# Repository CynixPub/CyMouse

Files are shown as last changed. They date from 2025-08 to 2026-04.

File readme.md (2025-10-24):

[中文版本 🇨🇳](./readme_cn.md)

# CyMouse: A High-Performance Mouse with Health Monitoring

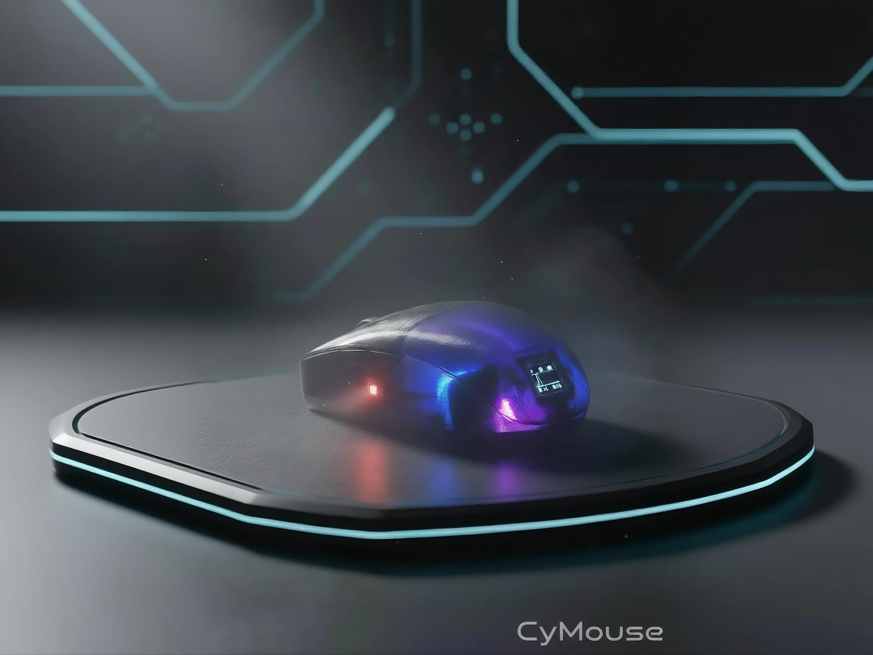
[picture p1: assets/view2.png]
CyMouse Preview


**CyMouse** is a high-performance mouse that supports health monitoring. It is powered by an **ESP32-S3FH4R2** controller and equipped with a **PAW3395DM-T6QU** sensor. It also integrates SpO₂ and heart rate sensors, as well as a built-in display for viewing mouse status and configuring settings.

---

## ✨ Background

Due to the nature of my work, I spend long hours sitting in front of a computer. This made me wonder — could there be a product that monitors our health unobtrusively?

Currently, most health monitoring devices are wristbands or smartwatches. However, I personally dislike wearing them while working because they often bump against the keyboard. Health monitoring sensors need close contact with the body — usually the wrist or fingers. In the workplace, the peripheral we touch the most is undoubtedly the **mouse**.

Thus, the idea of integrating health monitoring into a mouse was born — and that’s how **CyMouse** came to life.

---

## 🚀 Key Features

### 🖱️ Mouse Features

- **Tri-mode connectivity**: USB-C wired, Bluetooth, and 2.4G wireless.  
- **High-performance sensor**: PAW3395DM-T6QU sensor, up to 26,000 DPI.  
- **Quick DPI switching**: Dedicated DPI button on the bottom for easy adjustment.

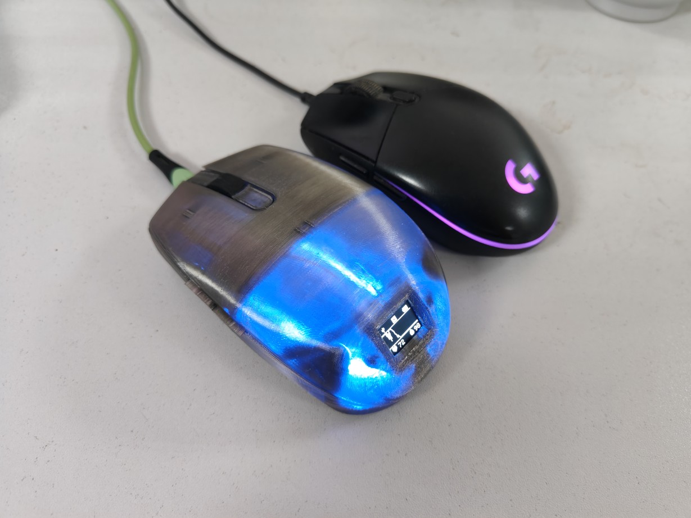
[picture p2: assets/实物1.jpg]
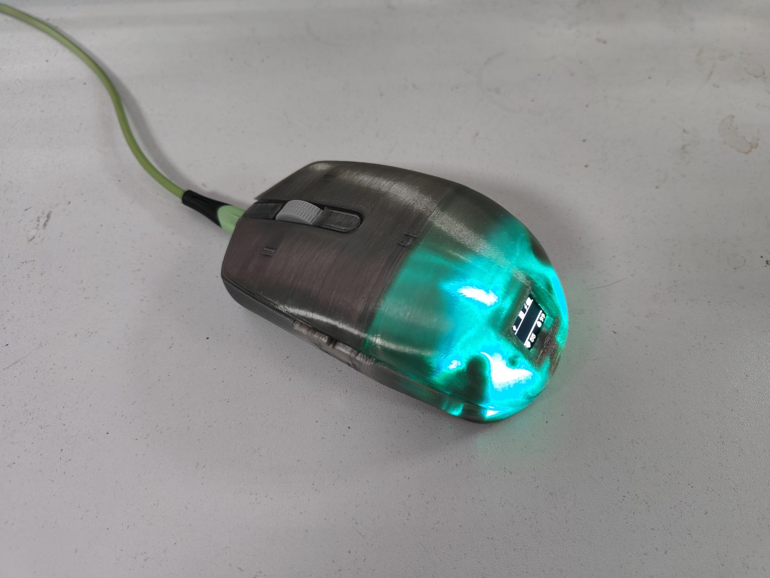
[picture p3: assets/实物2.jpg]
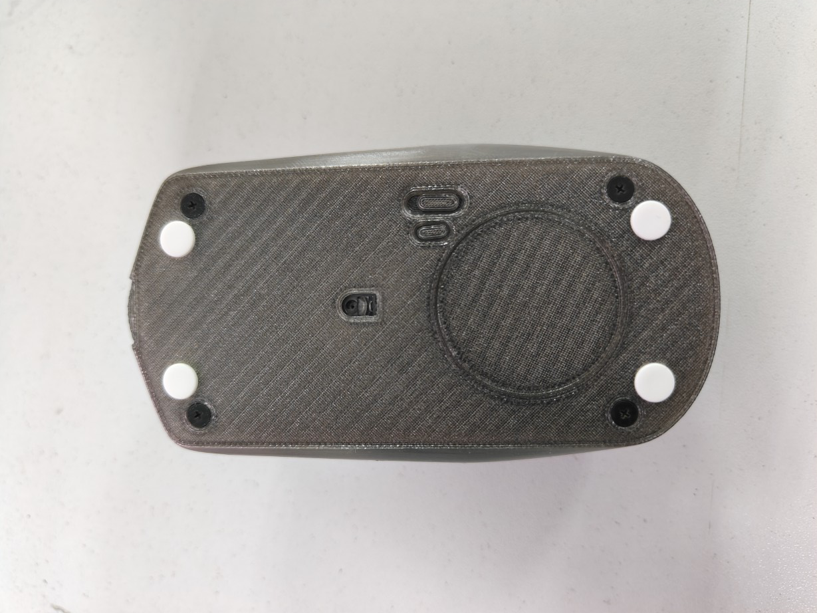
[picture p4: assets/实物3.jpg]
      

#### Performance Data

- **USB / Wireless Mode**:  
  Due to the ESP32-S3’s USB Full-Speed (12 Mbit/s) limitation, the maximum polling rate is 1 kHz. While this doesn’t fully unleash the PAW3395DM-T6QU’s capabilities, the actual experience is smoother and more precise than my Logitech G102 — more than enough for office use and gaming (including FPS titles).

  *(Performance charts omitted for brevity — same as original)*

- **Bluetooth Mode**:  
  Performance is slightly limited by BLE protocol constraints but is perfectly sufficient for office use.

  *(Performance charts omitted for brevity — same as original)*

- **Mouse Weight**:  
  Base weight: 83 g; with battery: approximately 110.4 g.

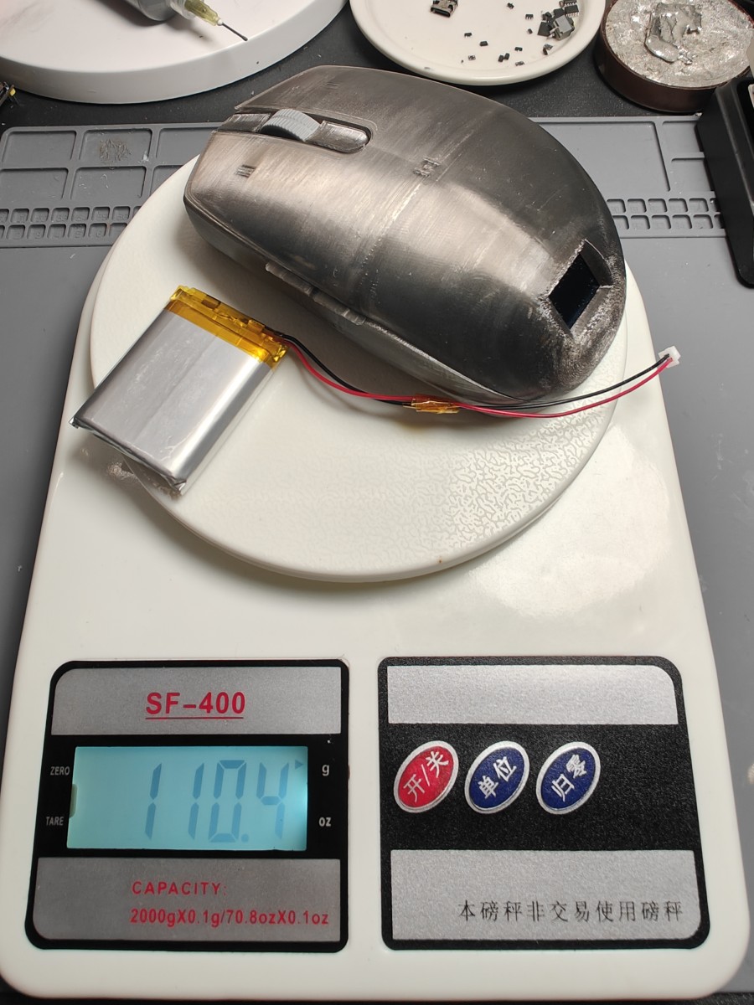
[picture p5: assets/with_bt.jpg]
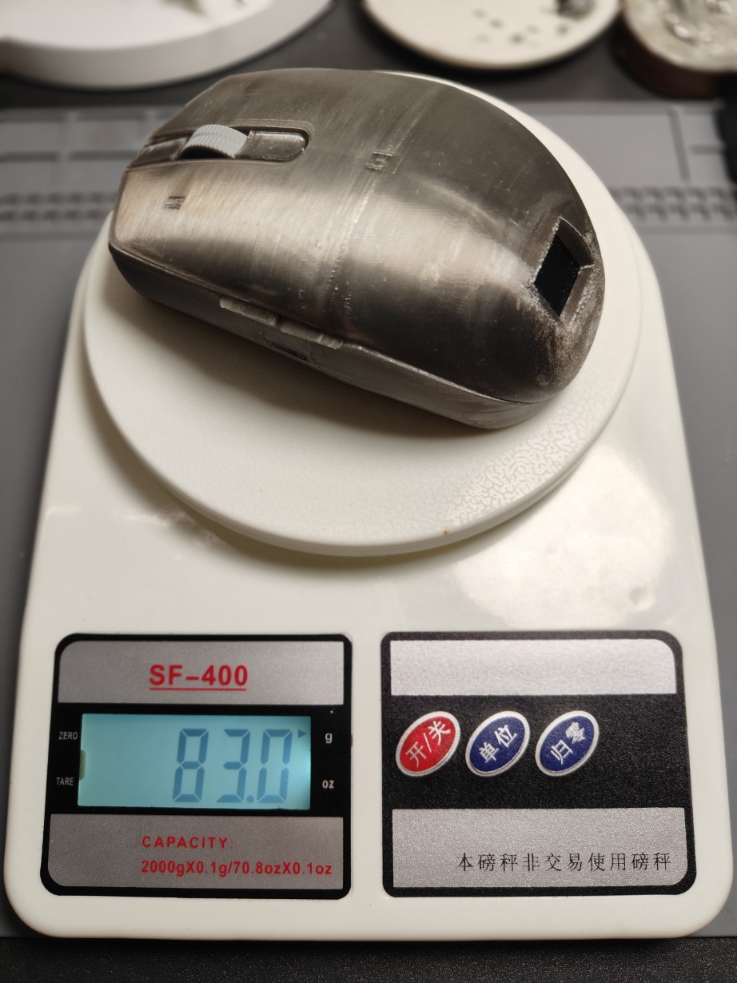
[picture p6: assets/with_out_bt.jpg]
   

---

### ❤️ Health Monitoring

- **Multi-dimensional data**: Supports SpO₂, heart rate, fatigue index, microcirculation, blood pressure, cardiac output, peripheral resistance, and more.  
- **Smart reminders**: Vibration-based sedentary alerts.

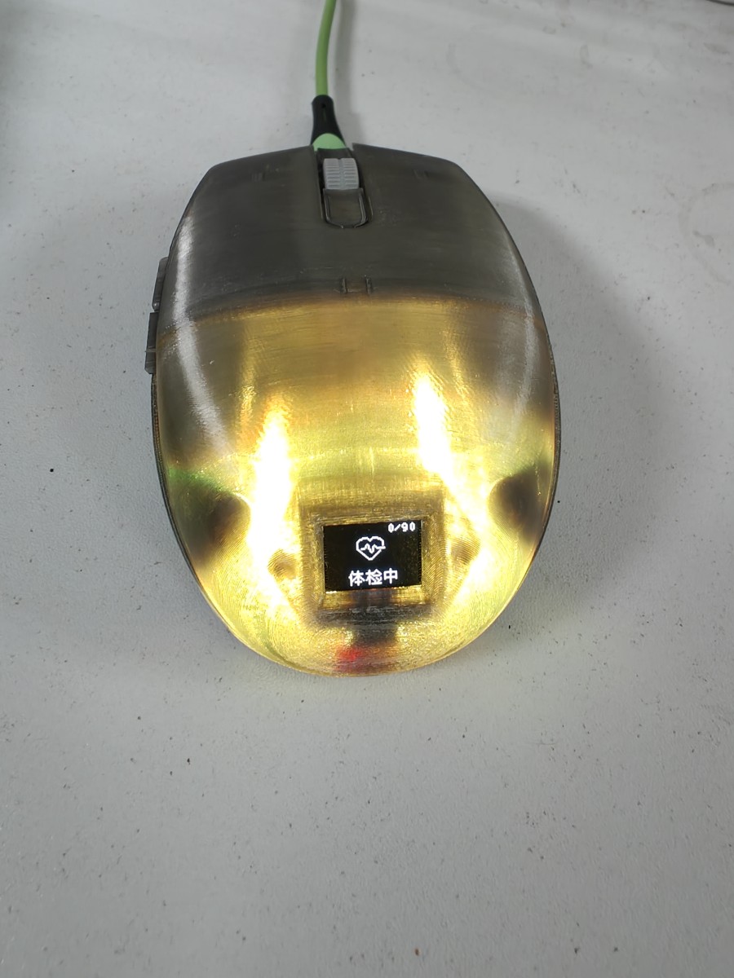
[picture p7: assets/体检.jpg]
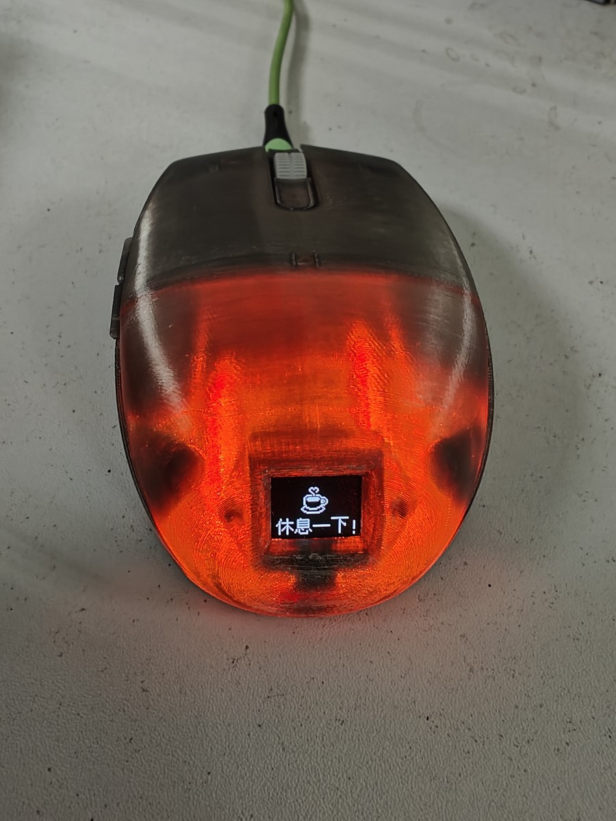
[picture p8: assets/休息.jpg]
   

*(Note: Current lighting effects use random colors.)*

---

### 💡 Additional Features

- Adjustable DPI and scroll speed  
- Customizable on-screen animations during movement  
- RGB lighting effects  
- Health and mouse data history  
- Multi-language support  

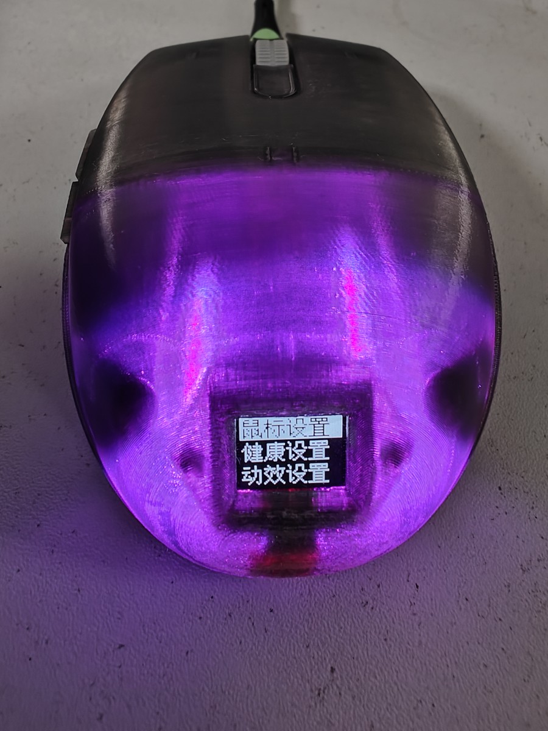
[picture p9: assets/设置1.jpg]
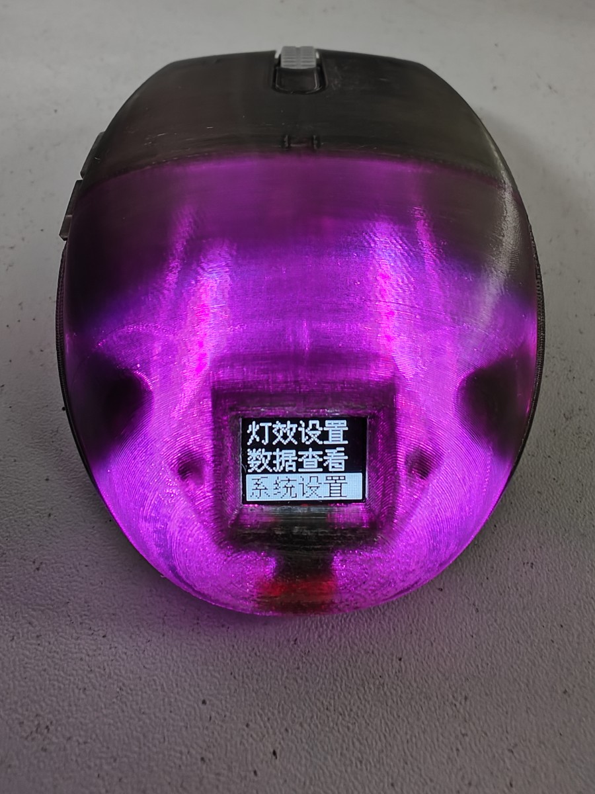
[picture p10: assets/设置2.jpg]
   

---

### 💻 PC Client

In USB mode, the PC client can:

- View historical health monitoring data  
- Manually initiate a new health check  
- Display usage statistics for the mouse  

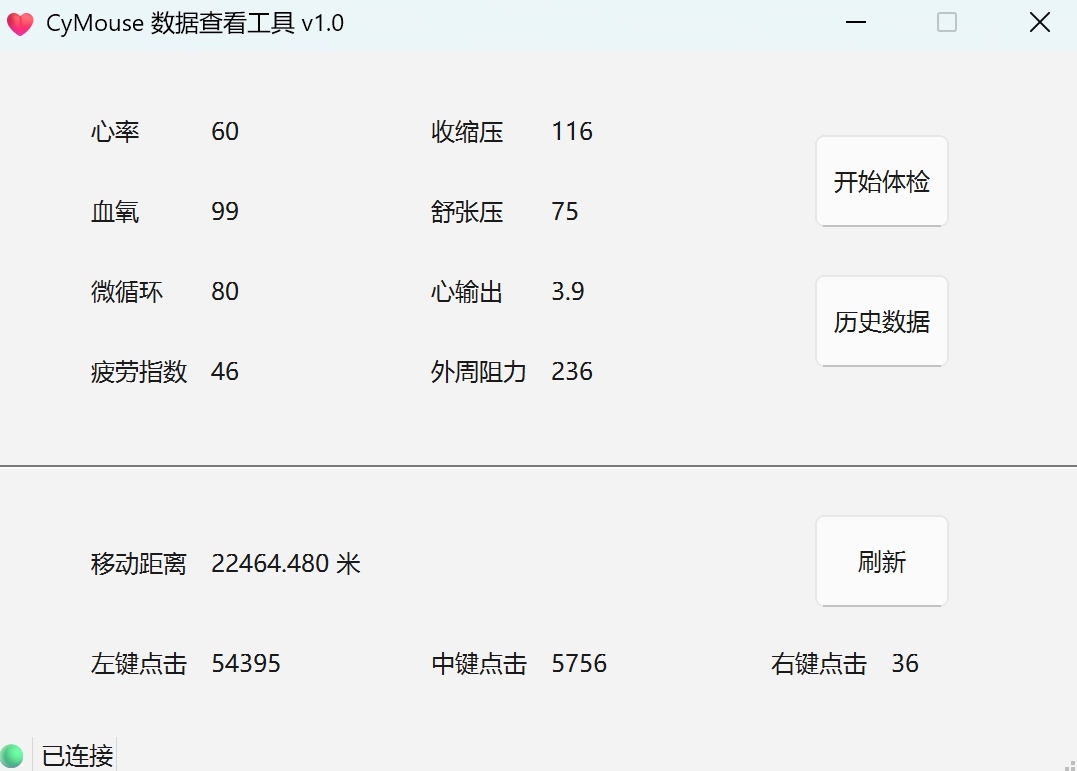
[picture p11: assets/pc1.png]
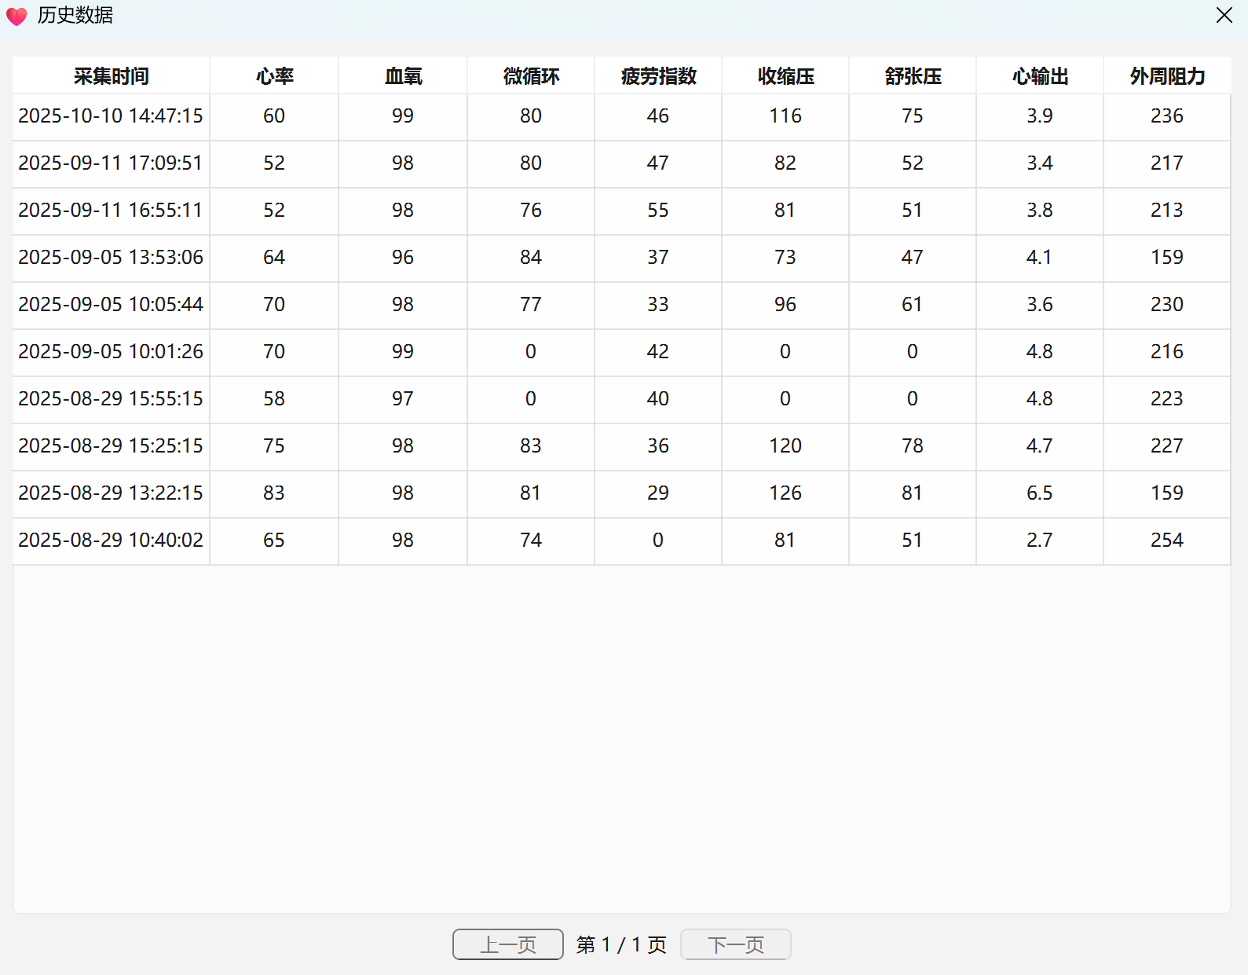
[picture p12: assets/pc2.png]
   

---

## 🛠️ Hardware Customization and Assembly

Hardware resources are open source. You can find them here:  
- **Open-source repository**: https://oshwlab.com/keivenliao/cymouse

### Procurement Notes

Most components are available on LCSC. If out of stock, you may source alternatives elsewhere. Special parts include:

- **Sensor**: PAW3395DM-T6QU (with lens model `LM19-LSI`)  
- **SpO₂ Module**: Custom module supporting blood pressure monitoring; includes 6-pin cable and 3D model matched to its dimensions  
- **Display**: 0.66" OLED, `64×48` resolution, `16PIN` interface (ensure connector matches reference image)  
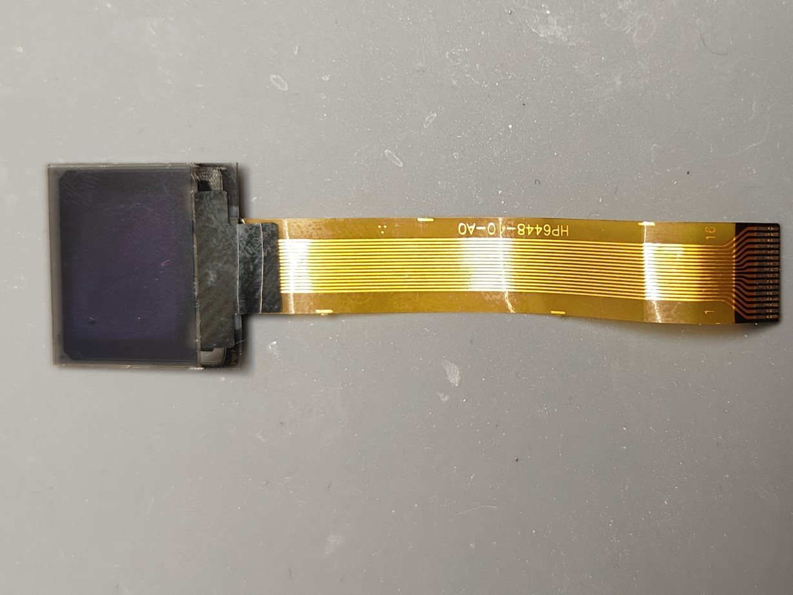
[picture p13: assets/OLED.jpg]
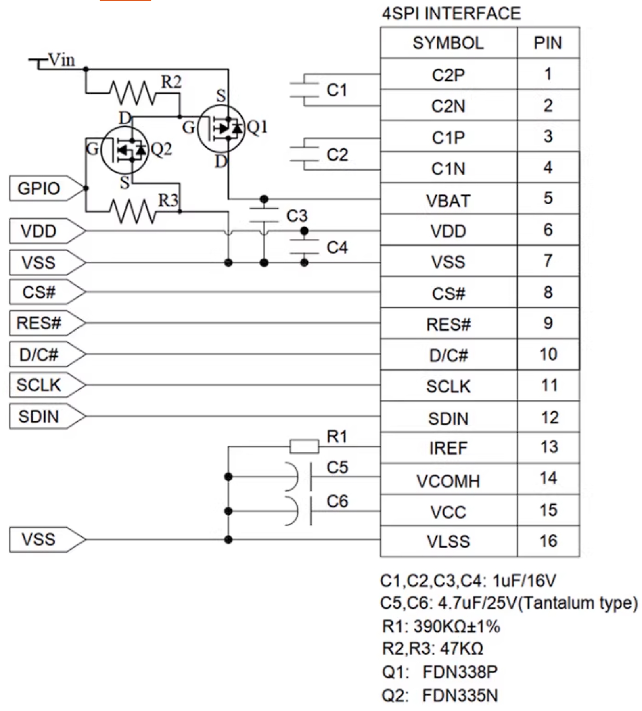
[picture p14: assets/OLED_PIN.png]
     
- **Battery**: `103443-1500mAh` (10×34×43 mm), ~48 hrs continuous use; optional if using USB mode only  
- **Battery Cable**: `2P 1.25mm` male, 50mm length  
- **USB Cable**: Flexible USB 2.0 Type-C for optimal wired performance  
- **Switches**: TTC Dustproof Gold (0.65N), or compatible  
- **Encoder**: TTC Dustproof Gold wheel encoder (12mm height)  
- **Middle Button**: Kailh Silent (9.5mm height)  
- **Scroll Wheel**: Compatible with Logitech G102 / G304 / G305  
- **Feet Pads**: 7mm diameter ice-type dots  
- **Screws and Nuts**: *(details same as original)*  
- **FPC Cable**: `4P`, `0.5mm` pitch, same direction, 5cm length  

### Soldering & Assembly Notes

- **Chip orientation**: Ensure `TPS61222DCKR` and both `TPS22919QDCKRQ1` chips align with PCB markings.  
- **Connector orientation**: Check 4-pin and 6-pin headers carefully.  
- **SpO₂ FPC cable**: Orientation **must** match the reference; incorrect direction may damage the module!  

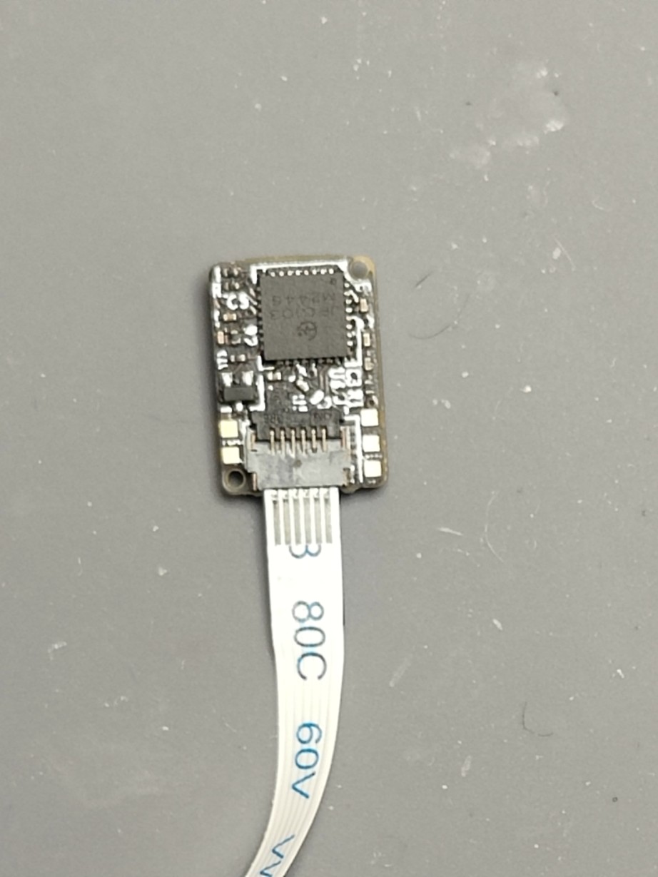
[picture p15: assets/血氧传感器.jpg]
  

---

### Core Circuit Design

- **Charging Chip**: TI `BQ24075RGTR` (supports power path management) instead of common `TP4056`.  
- **Main Power**: `TLV62569DBVR` DCDC instead of LDO for reduced heat and higher efficiency.  
- **RGB LED Power**: `TPS61222DCKR` boosts 3.3V→5V for stable illumination; combined with `TPS22919QDCKRQ1` load switch for MCU-controlled power-off.

---

### 3D Model & Printing

- Model split into top cover, top support, base, and small parts.  
- Designed in Autodesk Fusion 360 (source files provided).  
- Printable directly via included Bambu Studio project files.  
- Recommended material: **translucent PETG** for best LED lighting effects.  

*(Assembly and support adjustment details same as original)*

---

## 💾 Firmware Flashing & Usage

### Flashing Guide

- **Mouse firmware**: Flash the **full firmware** first. For later updates, use **upgrade firmware** to retain activation and history.  
- **Wireless receiver**: Any ESP32-S3 (with R2 Flash/RAM) board works. Receiver firmware is open-source and adaptable.  

### Activation

Firmware is closed-source. On first boot, scan the on-screen QR code to obtain a **free lifetime activation code**.

> **Tips**:
> - Avoid using WeChat scanner (browser limitation)  
> - Use your phone’s camera, browser, or Alipay  
> - If redirect fails, connect to Wi-Fi hotspot `CyMouse_xxxx` (password `12345678`) to auto-open activation page  
> - Retrieve activation code at: https://cynix.cc/license/activate  

### Usage

- **Enter Settings**: Hold both side buttons for 3 seconds.  

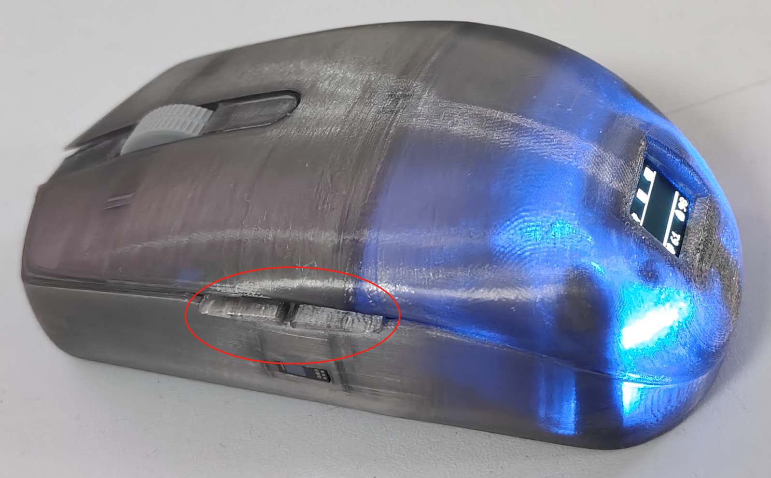
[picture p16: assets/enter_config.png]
  

---

### 🔋 Unverified Features

Hardware design includes wireless charging support with reserved module space, though it hasn’t been tested yet. Follow for updates.

---

## 📜 Open Source & Privacy

- **Open components**: Hardware (PCB), 3D model, receiver firmware, and PC client.  
  - Hardware: https://oshwhub.com/keivenliao/cymouse  
  - Receiver: https://github.com/CynixPub/CyMouse_Receiver  
  - PC Client: https://github.com/CynixPub/PC_monitor  
- **User Privacy**: Mouse firmware works fully offline; PC client stores data locally.  
- **Licenses**: CC BY-NC-SA 4.0 / GPLv3.

---

## 🙏 Acknowledgments

Inspired by the following projects:

- https://github.com/Ghost-Girls/PMW3360-3389-PAW3395_STM32-CH32-APM32  
- https://github.com/Li-Dongze/stm32_paw3395_mouse  
- https://github.com/kirltrz/PAW3395_Arduino_ESP32  

---

## ✍️ Final Words

Technically, the PC client could configure all mouse features, but that would defeat the purpose — I wanted all settings adjustable directly **on the mouse display**. (Also, I’ll admit... a bit of laziness 😄)

Hardware development isn’t easy — I’ve gone through countless trials, especially with 3D model fitting. Here are some of the **“sacrifices”** made along the way:

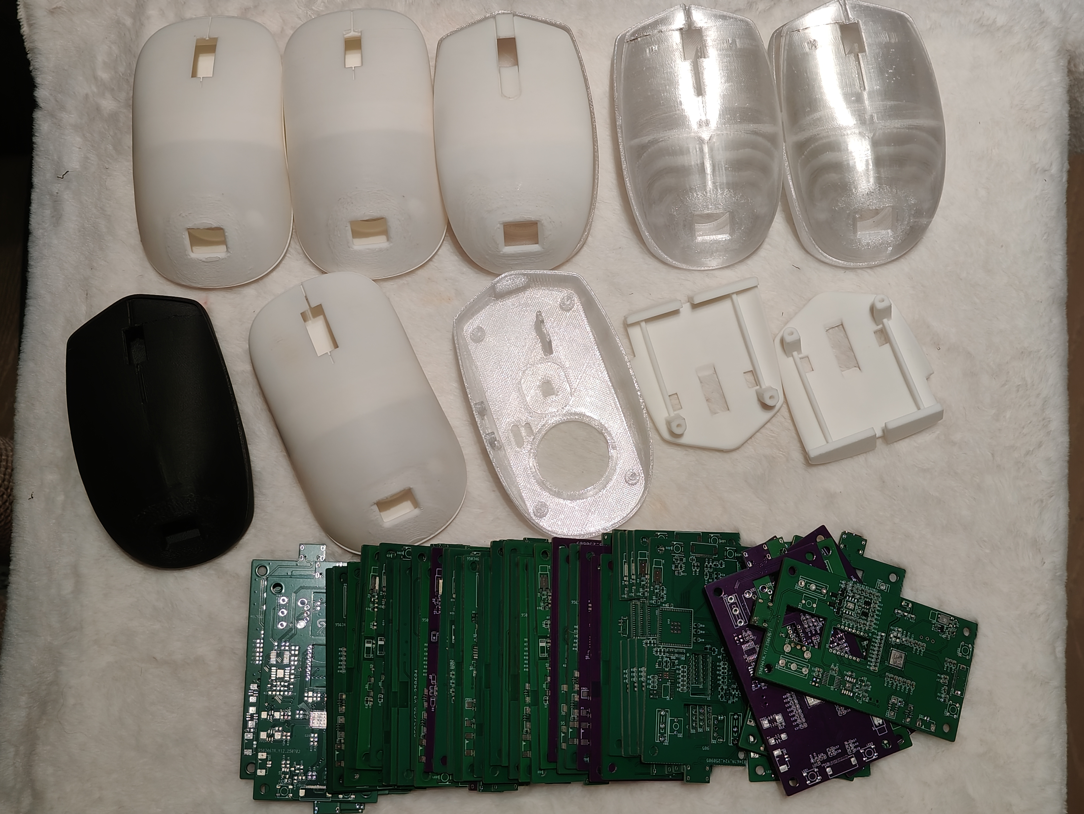
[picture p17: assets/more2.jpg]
  

---

## ❤️ Donation

If CyMouse has been helpful to you, consider supporting me — it helps improve and maintain this project.

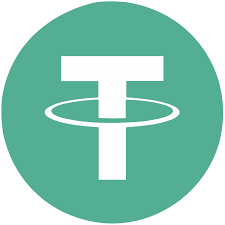
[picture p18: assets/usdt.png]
   TFexGjjxHDo7EsU6x8Yiz7Eu2kqVYpnEw1

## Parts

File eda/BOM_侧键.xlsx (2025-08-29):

No. | Quantity | Comment | Designator | Footprint | Value | Manufacturer Part | Manufacturer | Supplier Part | Supplier
1 | 1 | AFC01-S04FCC-00 | FPC1 | FFC-SMD_4P-P0.50_AFC01-S04FCC-00 |  | AFC01-S04FCC-00 | JS(钜硕电子) | C262260 | LCSC
2 | 2 | TS-1007S-AR02516 | SW23,SW24 | SW-SMD_L6.1-W3.6-LS7.9 |  | TS-1007S-AR02516 | XUNPU(讯普) | C720381 | LCSC

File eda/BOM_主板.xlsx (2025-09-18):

No. | Quantity | Comment | Designator | Footprint | Value | Manufacturer Part | Manufacturer | Supplier Part | Supplier
1 | 10 | 10uF | C1,C7,C16,C17,C18,C19,C24,C30,C33,C34 | C0603 | 10uF | CL10A106KP8NNNC | SAMSUNG(三星) | C19702 | LCSC
2 | 13 | 1uF | C2,C4,C8,C14,C21,C23,C25,C28,C32,C35,C36,C37,C38 | C0603 | 1uF | CL10A105KO8NNNC | SAMSUNG(三星) | C1592 | LCSC
3 | 10 | 100nF | C3,C6,C9,C10,C13,C20,C22,C27,C29,C31 | C0603 | 100nF | CL10B104JB8NNNC | SAMSUNG(三星) | C24452 | LCSC
4 | 6 | 4.7uF | C5,C11,C12,C15,C39,C40 | C0603 | 4.7uF | CL10A475KP8NNNC | SAMSUNG(三星) | C1705 | LCSC
5 | 1 | 47uF | C26 | CASE-A_3216 | 47uF | TAJA476K006RNJ | Kyocera AVX | C7190 | LCSC
6 | 1 | WAFER-MX1.25-2PLB | CN1 | CONN-SMD_P1.25_M1250VS-02P |  | WAFER-MX1.25-2PLB | XUNPU(讯普) | C3029350 | LCSC
7 | 2 | CUS10S30,H3F | D1,D2 | SOD-323_L1.8-W1.3-LS2.5-RD |  | CUS10S30,H3F | TOSHIBA(东芝) | C146335 | LCSC
8 | 1 | USBLC6-2SC6 | D3 | SOT-23-6_L2.9-W1.6-P0.95-LS2.8-BL |  | USBLC6-2SC6 | TECH PUBLIC(台舟) | C2827654 | LCSC
9 | 1 | TS3315A | DPI1 | SW-SMD_4P-L3.4-W3.4-P2.00-LS4.0 |  | TS3315A | SHOU HAN(首韩) | C412367 | LCSC
10 | 1 | X05C2004TZ-518 | FPC1 | FPC-SMD_4P-P0.50_X05C2004TZ |  | X05C2004TZ-518 | XKB Connection(中国星坤) | C397314 | LCSC
11 | 1 | AFC11-S06ICA-00 | FPC2 | FPC-SMD_6P-P0.50_AFC11-S06ICA-00 |  | AFC11-S06ICA-00 | JS(钜硕电子) | C262496 | LCSC
12 | 1 | FPC-05F-16PH20 | FPC3 | FPC-SMD_16P-P0.50_FPC-05F-16PH20 |  | FPC-05F-16PH20 | XUNPU(讯普) | C2856801 | LCSC
13 | 1 | 2.2uH | L1 | L0603 | 2.2uH | LQM18PN2R2MFRL | muRata(村田) | C337910 | LCSC
14 | 1 | 4.7uH | L2 | L0603 | 4.7uH | LQM18PN4R7MFRL | muRata(村田) | C114862 | LCSC
15 | 2 | WS2812B-B/T | LED1,LED2 | LED-SMD_4P-L5.0-W5.0-TL_WS2812B-B |  | WS2812B-B/T | worldsemi | C2761795 | LCSC
16 | 1 | Z3OC1T8219731 | M1 | VIBRATING-MOTOR-SMD_3P-C9900001680 |  | Z3OC1T8219731 | KOTL(金龙机电) | C2894731 | LCSC
17 | 2 | AO3401 | Q1,Q2 | SOT-23-3_L2.9-W1.4-P1.90-LS2.6-BR |  | AO3401 | TWGMC(迪嘉) | C727156 | LCSC
18 | 2 | S8050 J3Y(RANGE:200-350) | Q3,Q4 | SOT-23-3_L3.0-W1.7-P0.95-LS2.9-BR |  | S8050 J3Y(RANGE:200-350) | CJ(江苏长电/长晶) | C2146 | LCSC
19 | 1 | AO3400A | Q5 | SOT-23-3_L2.9-W1.3-P1.90-LS2.4-BR |  | AO3400A | UMW(友台半导体) | C347475 | LCSC
20 | 4 | 5.1kΩ | R1,R4,R25,R26 | R0603 | 5.1kΩ | 0603WAF5101T5E | UNI-ROYAL(厚声) | C23186 | LCSC
21 | 1 | 47kΩ | R2 | R0603 | 47kΩ | FRC0603F4702TS | FOJAN(富捷) | C2907042 | LCSC
22 | 5 | 100kΩ | R3,R5,R9,R19,R21 | R0603 | 100kΩ | 0603WAF1003T5E | UNI-ROYAL(厚声) | C25803 | LCSC
23 | 2 | 1.2kΩ | R6,R8 | R0603 | 1.2kΩ | 0603WAF1201T5E | UNI-ROYAL(厚声) | C22765 | LCSC
24 | 4 | 10kΩ | R7,R15,R16,R17 | R0603 | 10kΩ | 0603WAF1002T5E | UNI-ROYAL(厚声) | C25804 | LCSC
25 | 2 | 4.7kΩ | R10,R11 | R0603 | 4.7kΩ | 0603WAF4701T5E | UNI-ROYAL(厚声) | C23162 | LCSC
26 | 1 | 499kΩ | R12 | R0603 | 499kΩ | 0603WAF4993T5E | UNI-ROYAL(厚声) | C26751 | LCSC
27 | 1 | 453kΩ | R13 | R0603 | 453kΩ | 0603WAF4533T5E | UNI-ROYAL(厚声) | C25818 | LCSC
28 | 1 | 5.6Ω | R14 | R0603 | 5.6Ω | 0603WAF560KT5E | UNI-ROYAL(厚声) | C23191 | LCSC
29 | 2 | 470Ω | R18,R20 | R0603 | 470Ω | 0603WAF4700T5E | UNI-ROYAL(厚声) | C23179 | LCSC
30 | 2 | 300kΩ | R22,R23 | R0603 | 300kΩ | 0603WAF3003T5E | UNI-ROYAL(厚声) | C23024 | LCSC
31 | 1 | 390kΩ | R24 | R0603 | 390kΩ | 0603WAF3903T5E | UNI-ROYAL(厚声) | C23150 | LCSC
32 | 2 | 10kΩ | RN1,RN2 | RES-ARRAY-SMD_0603-8P-L3.2-W1.6-BL | 10kΩ | YC164-FR-0710KL | YAGEO(国巨) | C110924 | LCSC
33 | 1 | CH334R | U1 | QSOP-16_L4.9-W3.9-P0.64-LS6.0-BL |  | CH334R | WCH(南京沁恒) | C4154405 | LCSC
34 | 1 | BQ24073RGTR | U2 | QFN-16_L3.0-W3.0-P0.50-TL-EP1.7 |  | BQ24073RGTR | TI(德州仪器) | C15220 | LCSC
35 | 1 | CH340K | U4 | ESOP-10_L4.9-W3.9-P1.00-LS6.2-BL-EP |  | CH340K | WCH(南京沁恒) | C968586 | LCSC
36 | 1 | TLV62569DBVR | U5 | SOT-23-5_L3.0-W1.7-P0.95-LS2.8-BR |  | TLV62569DBVR | TI(德州仪器) | C141836 | LCSC
37 | 1 | TLV70019DDCR | U6 | SOT-23-5_L2.9-W1.6-P0.95-LS2.8-BR |  | TLV70019DDCR | TI(德州仪器) | C2862411 | LCSC
38 | 1 | ESP32-S3-MINI-1-N4R2 | U7 | BULETM-SMD_ESP32-S3-MINI-1-N8 |  | ESP32-S3-MINI-1-N4R2 | ESPRESSIF(乐鑫) | C3013941 | LCSC
39 | 2 | TPS22919QDCKRQ1 | U8,U10 | SC-70-6_L2.0-W1.3-P0.65-LS2.1-BR |  | TPS22919QDCKRQ1 | TI(德州仪器) | C2871558 | LCSC
40 | 1 | TPS61222DCKR | U9 | SC-70-6_L2.2-W1.3-P0.65-LS2.1-BR |  | TPS61222DCKR | TI(德州仪器) | C116461 | LCSC
41 | 1 | MSS12C02LS-BB2.0 | U11 | SW-SMD_MSS12C02LS-HB2.0-1 |  | MSS12C02LS-BB2.0 | SHOU HAN(首韩) | C3008585 | LCSC
42 | 1 | TYPE-C 16PIN 2MD(073) | USB1 | USB-C-SMD_TYPE-C-6PIN-2MD-073 |  | TYPE-C 16PIN 2MD(073) | SHOU HAN(首韩) | C2765186 | LCSC
43 | 1 | 12MHz | X1 | CRYSTAL-SMD_4P-L2.5-W2.0-BL-A | 12MHz | X252012MMB4SI-24 | YXC(扬兴晶振) | C2896601 | LCSC

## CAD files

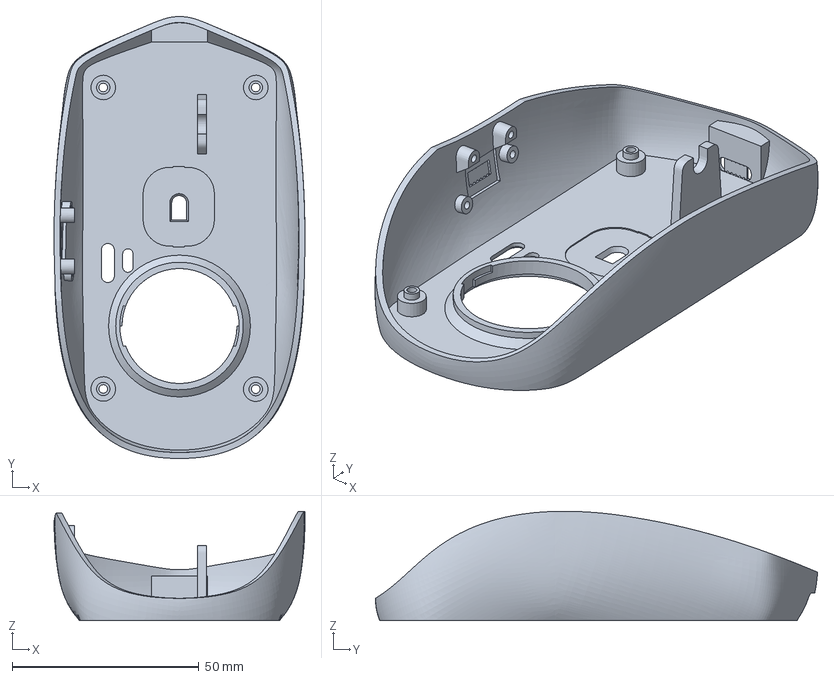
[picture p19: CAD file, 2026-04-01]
bambu/底.3mf
67.3 x 118.5 x 29.3 mm

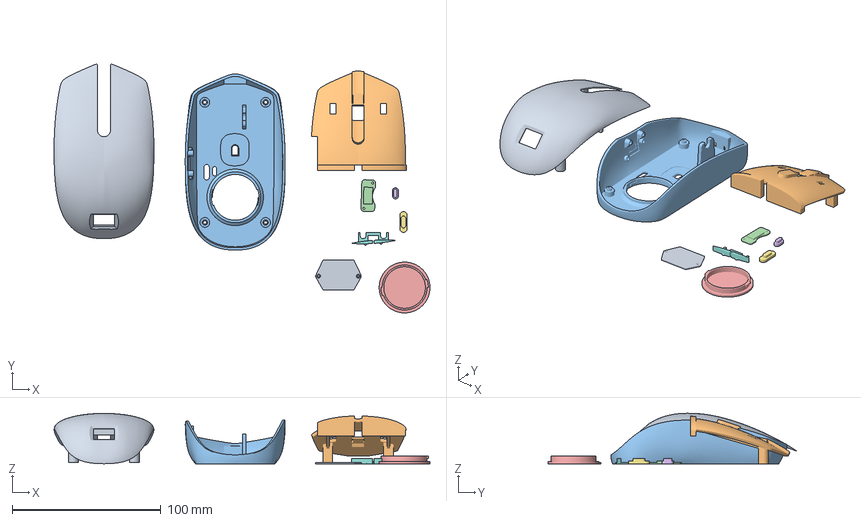
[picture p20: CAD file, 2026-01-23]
bambu/放在一个盘(仅展示).3mf
252.9 x 167.4 x 34.0 mm
上盖
上盖支撑
底
H盖板
底盖板
DPI 按钮
开关
侧键
屏幕盖板

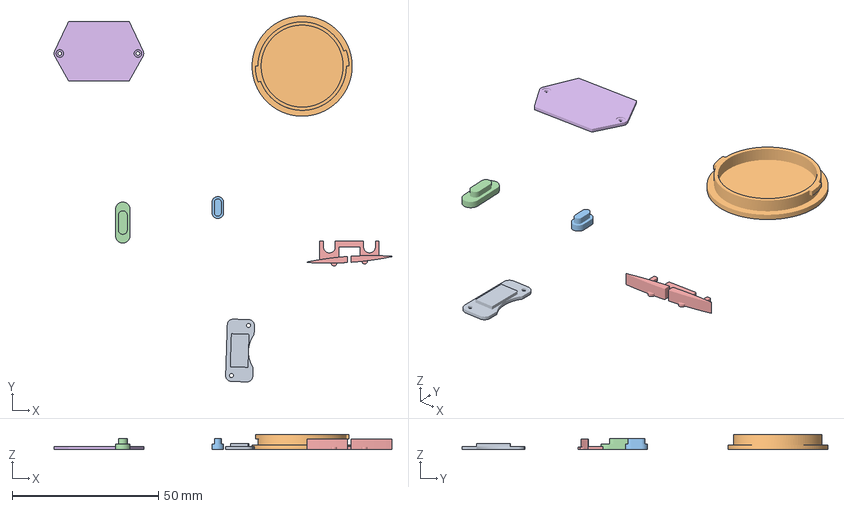
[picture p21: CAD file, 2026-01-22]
bambu/零件.3mf
115.4 x 124.9 x 5.08 mm
H盖板
底盖板
DPI 按钮
开关
侧键
屏幕盖板

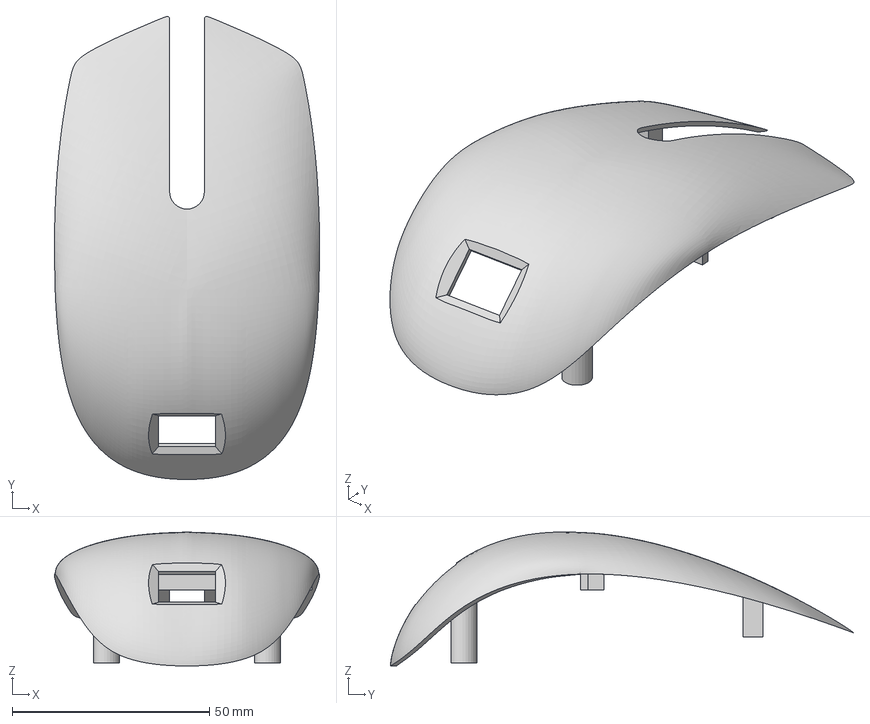
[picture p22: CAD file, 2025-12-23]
bambu/上盖.3mf
67.3 x 117.4 x 34.0 mm

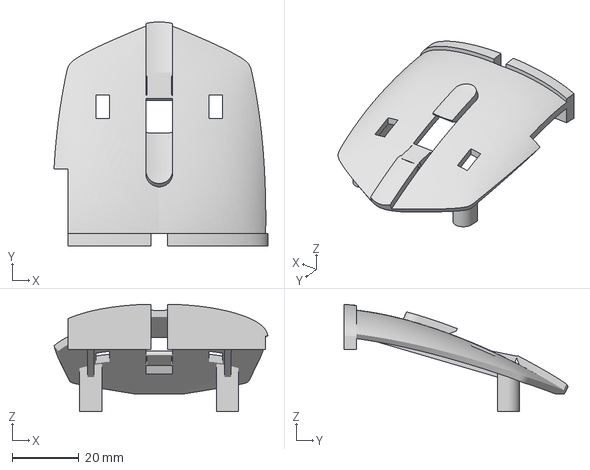
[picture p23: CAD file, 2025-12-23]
bambu/上盖支撑.3mf
63.9 x 66.9 x 32.1 mm

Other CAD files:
fusion360/CyMouse_(fusion360).f3z

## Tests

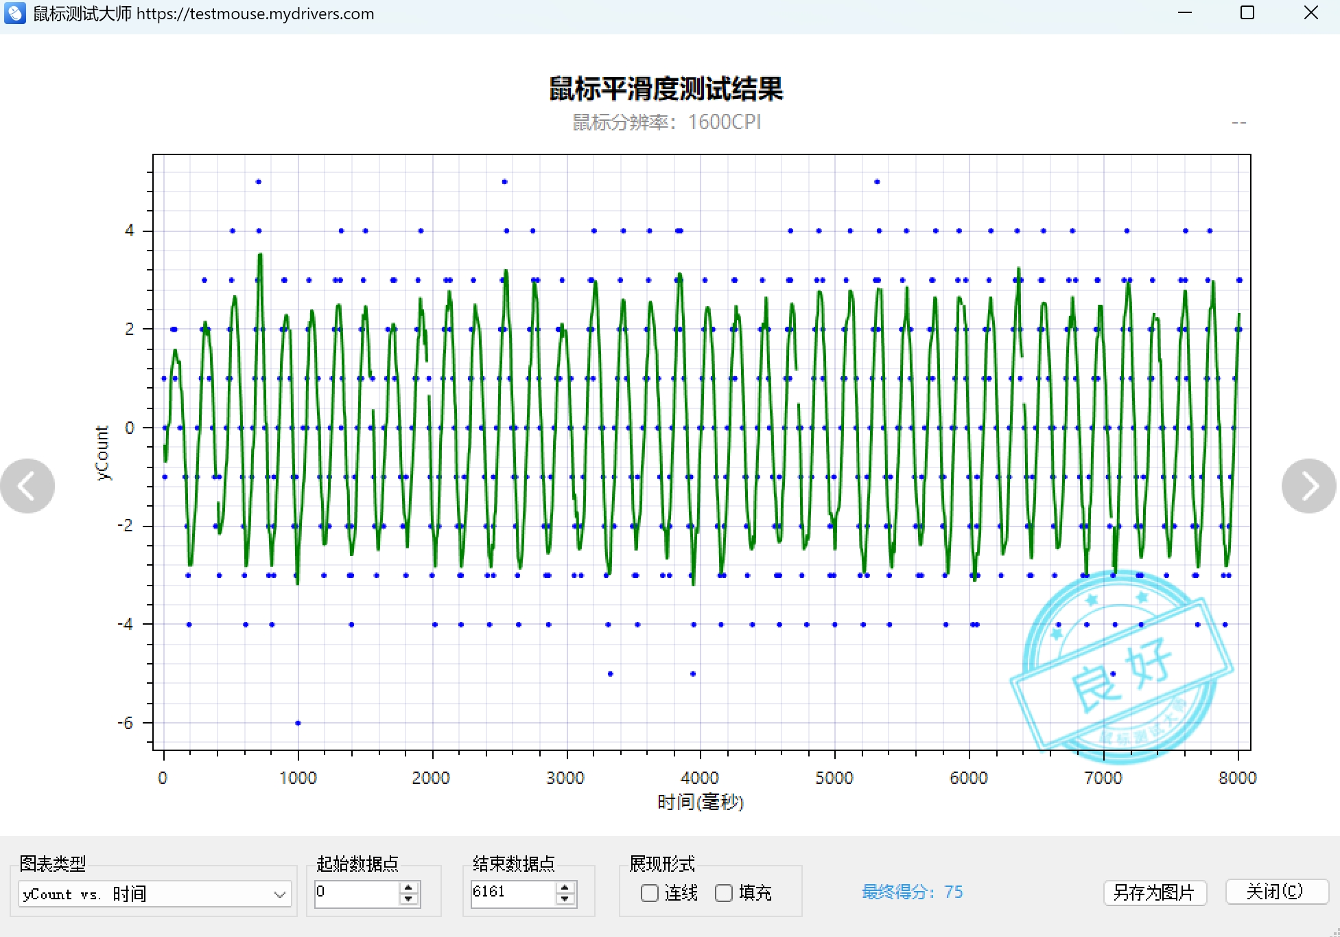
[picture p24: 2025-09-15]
assets/ble_test/yCount_vs_Time.png

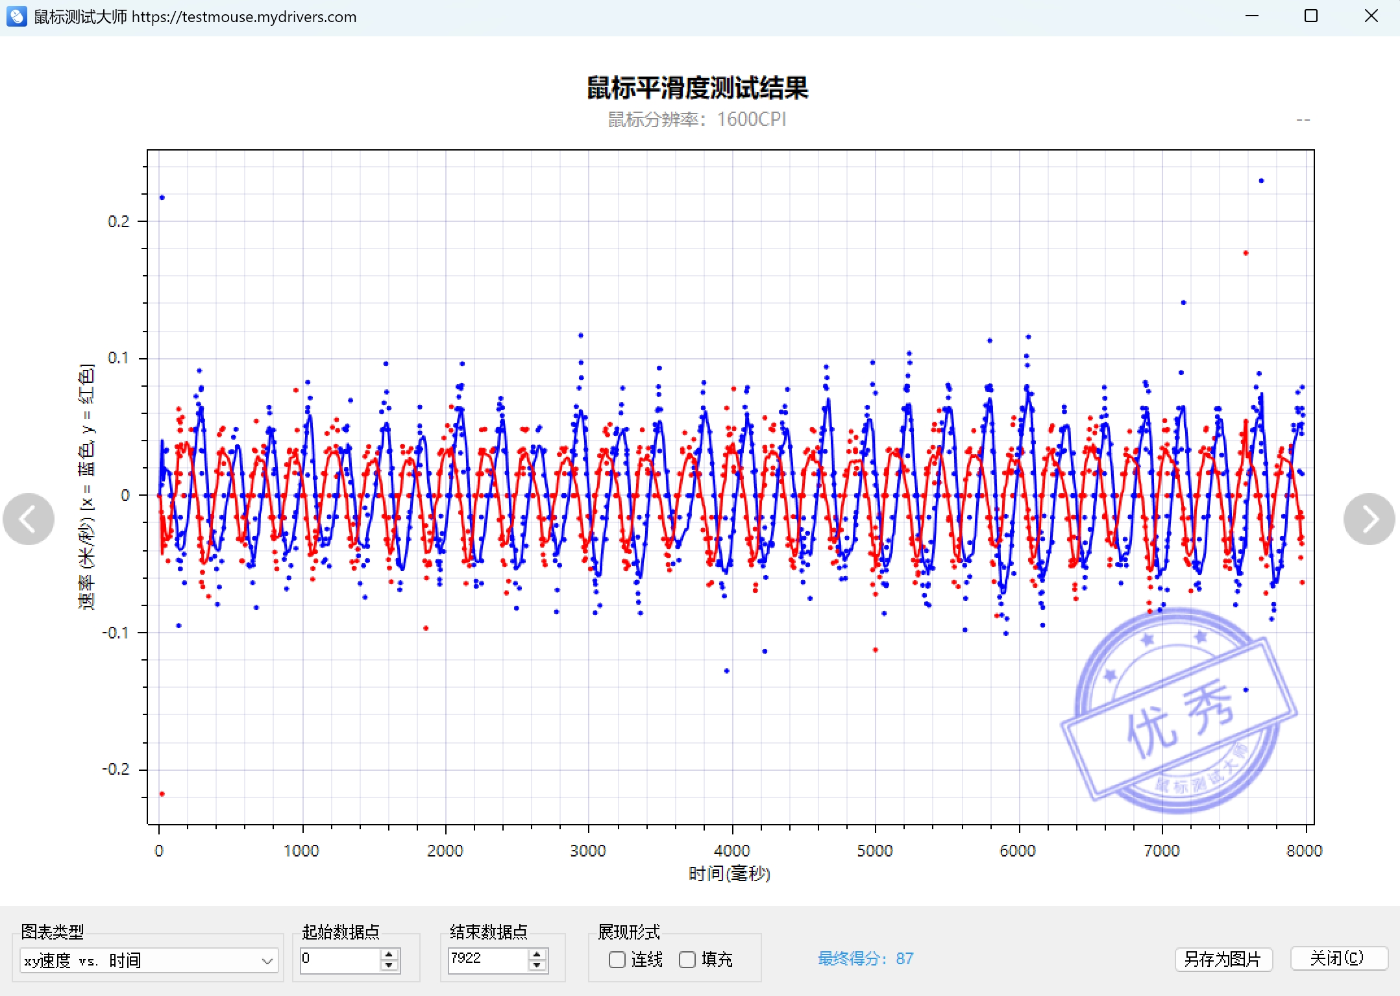
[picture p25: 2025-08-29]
assets/usb_test/xySpeed_vs_Time.png

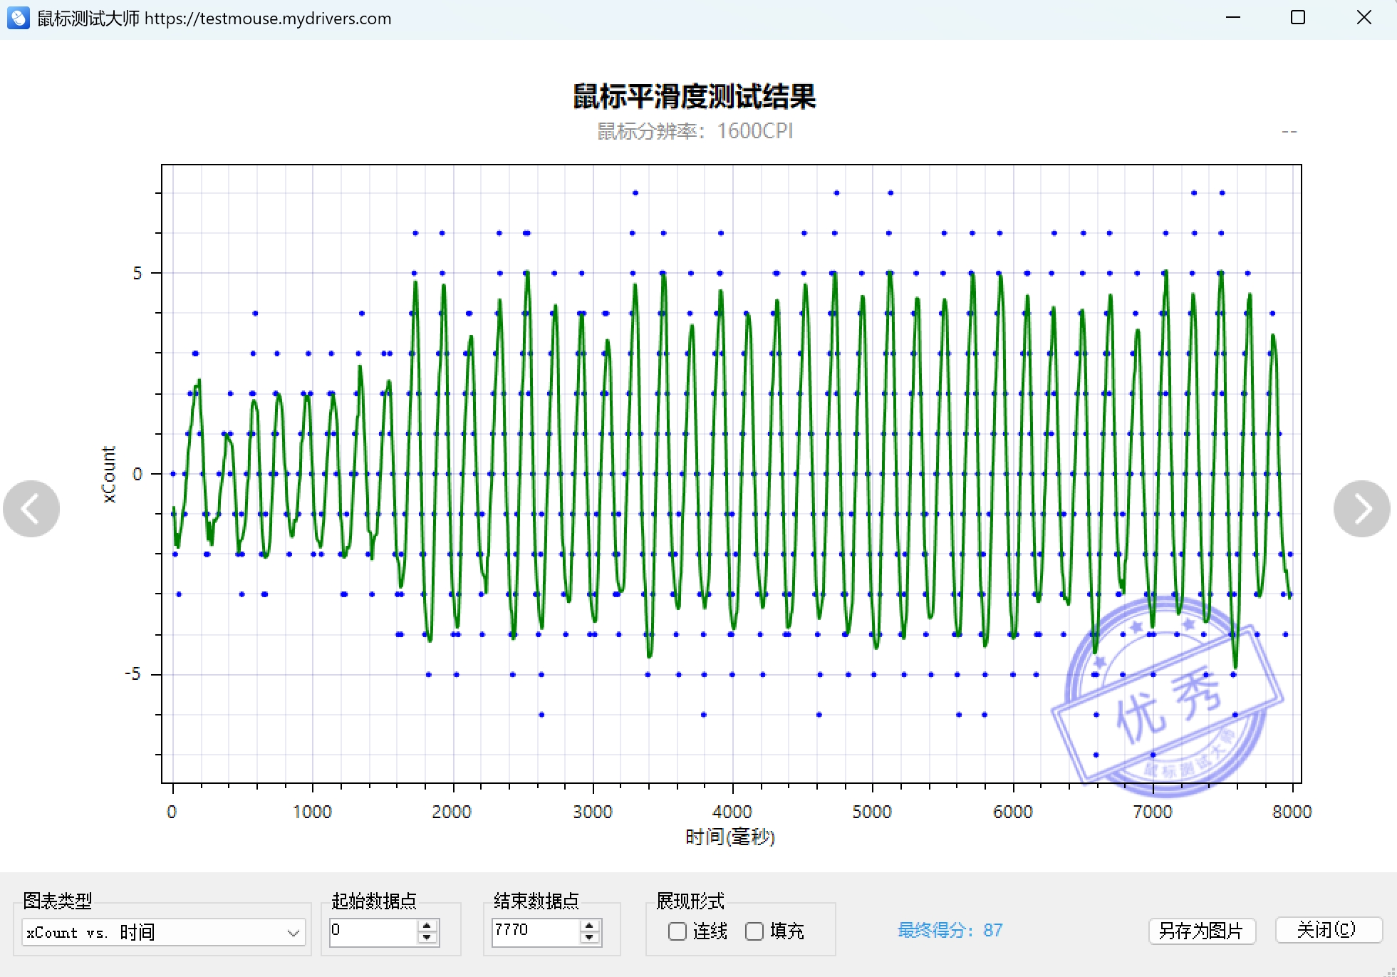
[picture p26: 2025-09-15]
assets/esp-now_test/xCount_vs_Time.png

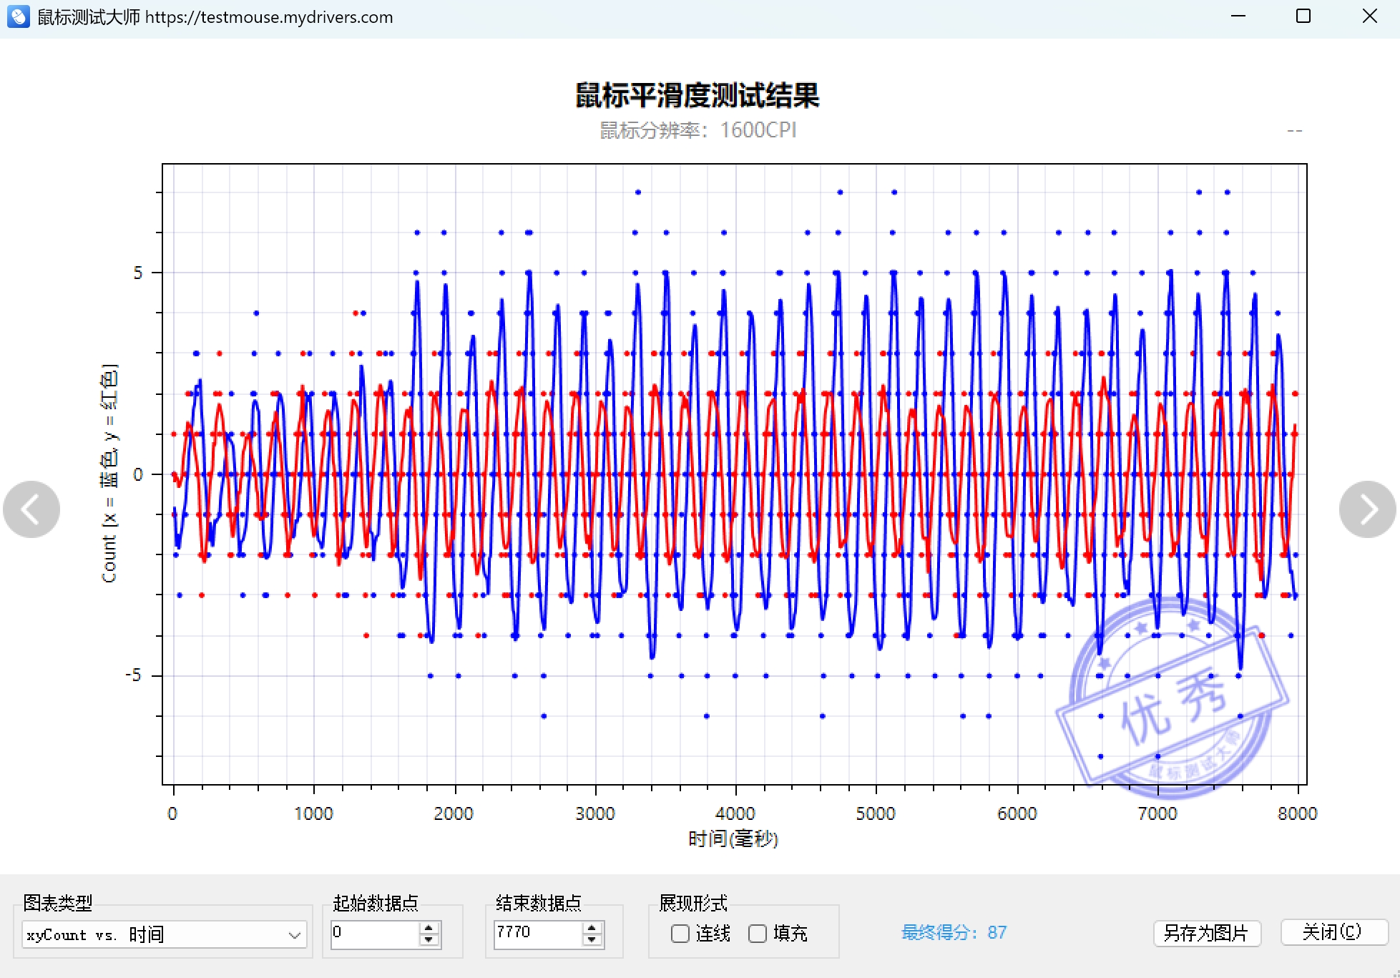
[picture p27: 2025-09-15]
assets/esp-now_test/xyCount_vs_Time.png

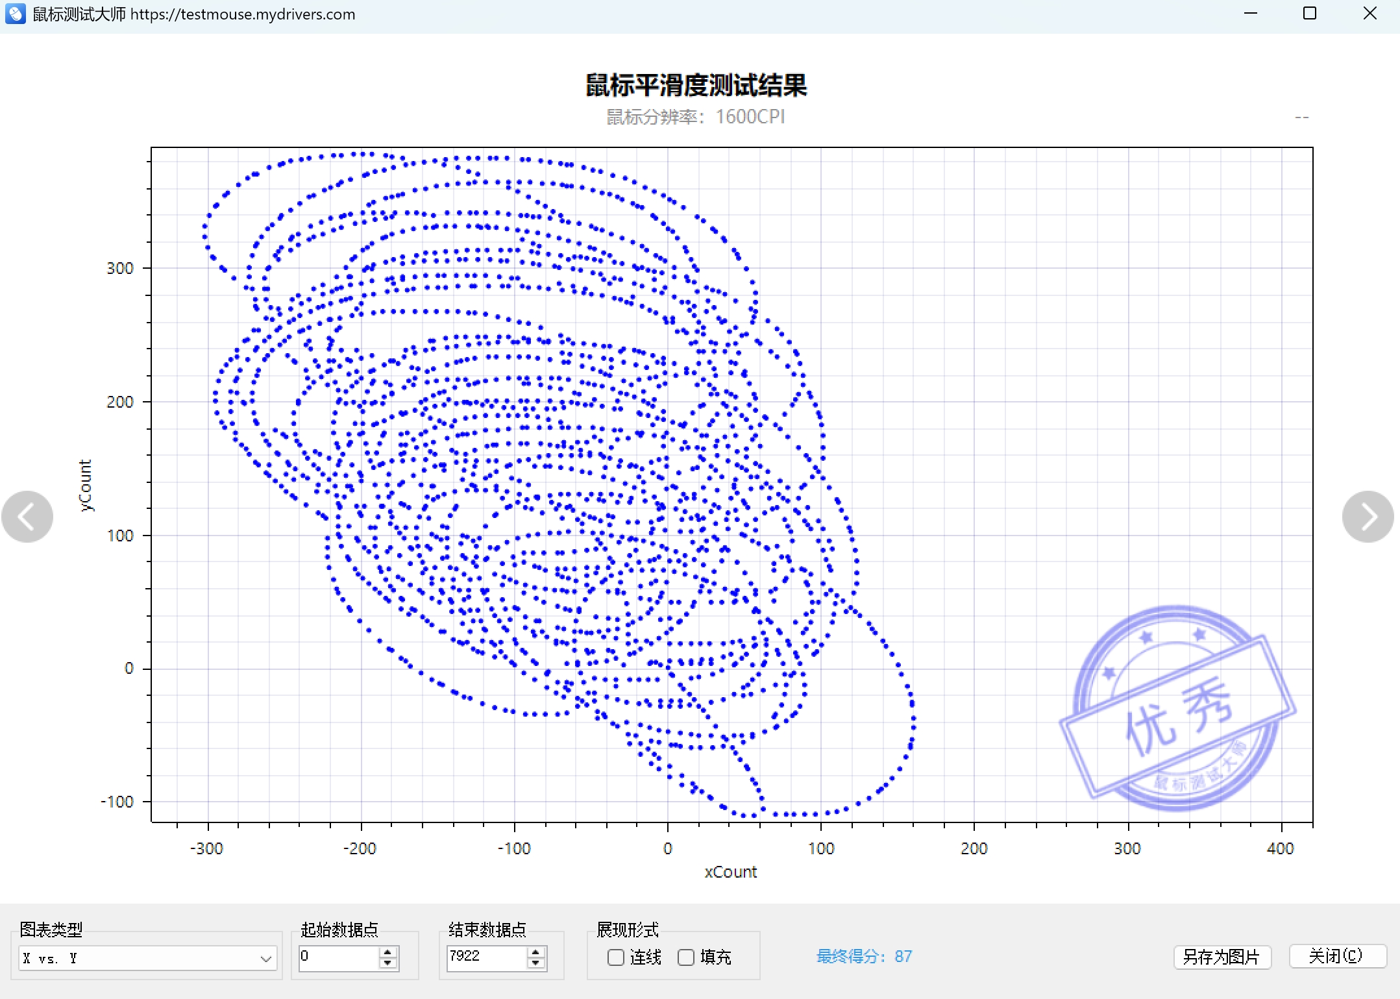
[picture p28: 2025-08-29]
assets/usb_test/x_vs_y.png

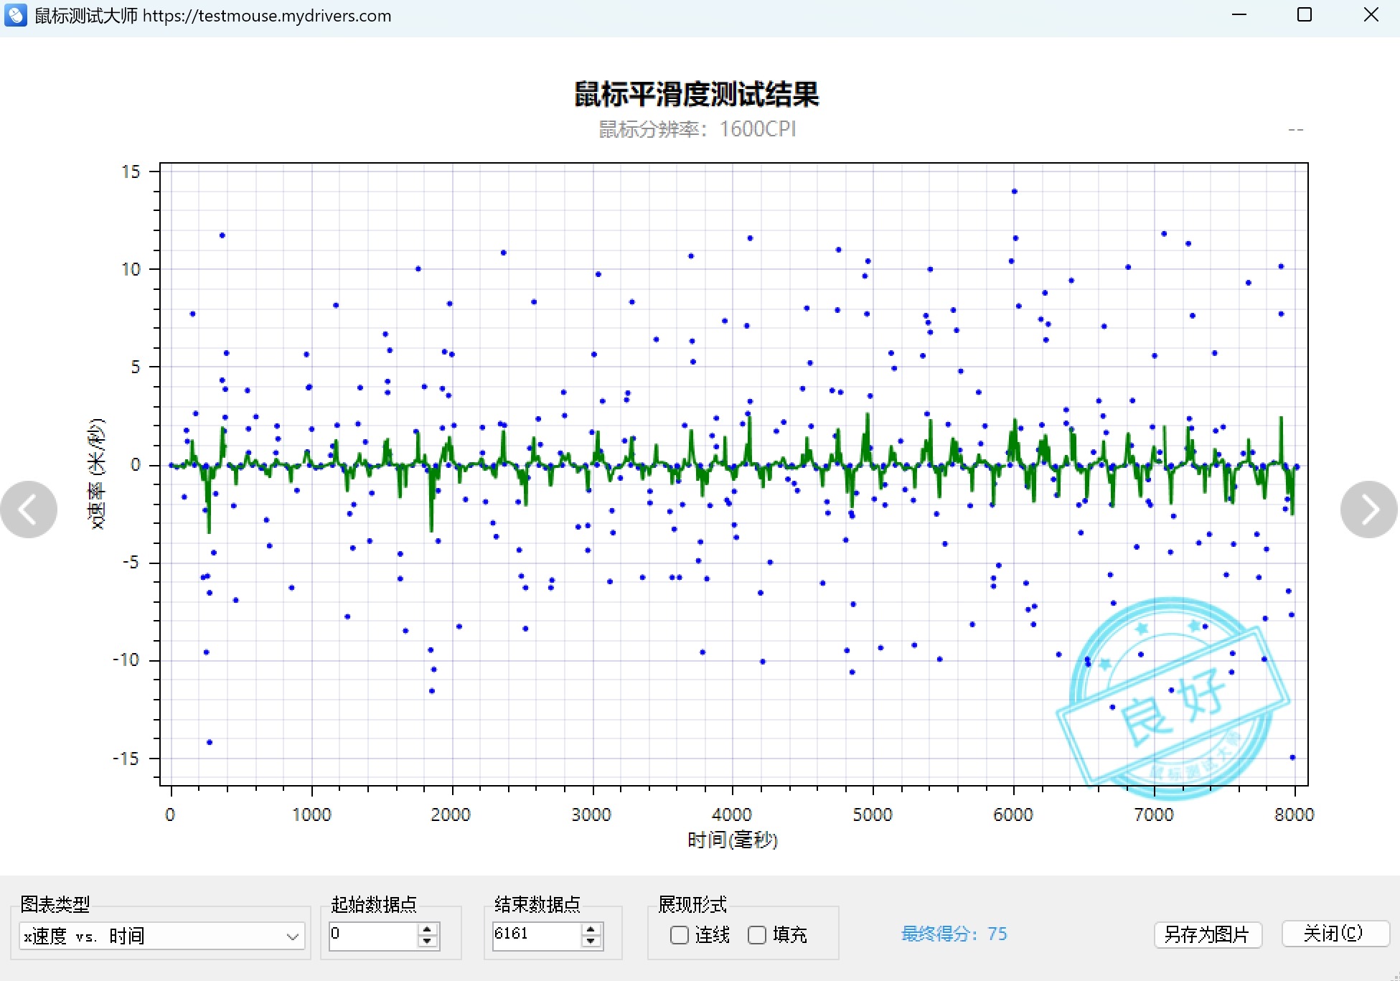
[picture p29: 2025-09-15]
assets/ble_test/xSpeed_vs_Time.png

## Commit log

2025-08-29 add model
    [上盖.3mf, 底.3mf, 零件.3mf]
2025-09-02 开始写文档
2025-09-02 补充配图，和完善文档
    [3D_主板.f3d, 3D_侧键.f3d, 3d_model.f3z]
2025-09-15 添加图片
